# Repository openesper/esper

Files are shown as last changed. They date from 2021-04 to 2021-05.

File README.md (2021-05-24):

Imgur

# About Esper

Heavily inspired by the [Pi-Hole](https://github.com/pi-hole/pi-hole), this project aims to bring network wide ad-blocking to another popular device popular among makers and hobbyists, the ESP32.

## What is DNS?

Commonly referred to as the "phone book for the internet", the DNS protocol is how devices map human readable urls like google.com or facebook.com into IP addresses that the device can use.

## How does Esper block ads?

Just like the [Pi-Hole](https://github.com/pi-hole/pi-hole), Esper acts as a DNS server for devices. When sent a DNS query, Esper will read the url the device is requesting, then decide to block the request by returning 0.0.0.0 or forward the request on to a real DNS server.

## Differences between Pi-hole and Esper

The biggest, and most obvious difference is the hardware these projects run on. Pi-hole aims to be available on any Linux powered hardware, while Esper is an ESP32 specific project. Due to being run on a microcontroller, Esper is much more limited in it's capabilities and is therefore much more minimal in it's design.

## Why choose Esper instead of Pi-hole?

Choose whatever one suits you! If you like tinkering with hardware, and do not have much experience with the Raspberry Pi/Linux ecosystem, setting up the Esper software on an ESP32 dev board might be an interesting project. And while Esper may not be nearly as powerful as a Raspberry Pi, DNS protocol is very lightweight in nature. Unless you are in a household with 10+ people that are always online you will likely never going to need more computing power than a microcontroller can provide.

At the same time, if you have no problem using a shell and Linux environment, the Pi-hole is a much more feature rich and powerful piece of software that is a joy to use.

## How can I get an Esper?

The easiest way, is to purchase a pre-made one from the [Tindie store](https://www.tindie.com/products/esper/esper/).

If you have some ESP32 development boards collecting dust, it will work on those too! ([Just follow the instructions here!](https://github.com/openesper/esper/blob/main/software/README.md))

DISCLAIMER: It is **heavily** recommended to use a device with ethernet. Even the best Wifi will significantly increase latency and decrease reliability compared to a good copper connection.

If you want to try you hand an making an Esper from scratch, the repository contains all the schematic, pcb, and enclosure files needed to build one yourself.

## Reprogramming Esper

Do you like the Esper hardware, but want to use it for something other than ad-blocking? Great! The Esper hardware is completely reprogrammable and includes an on-board USB-UART converter, no extra programmers are needed!

# Esper Development

## Tools Used

* KiCAD	- EDA tool used to design PCB
* FreeCAD - 3D modeling tool for designing enclosure
* ESP-IDF - Contains ESP32 API and build tools for firmware development
* Python 3.7 - Scripts to glue everything together

## Directory Structure

    ├── hardware                    # Hardware root directory
    │   ├── custom components           # Custom KiCad component files
    │   ├── enclosure                   # FreeCAD project and STL files for enclosure
    │   ├── product                     # KiCad projects for Esper
    │   │   ├── usb-programmable        	# Includes CP2102 for easy usb programming
    │   │   └── jtag-header             	# 10-pin header for JTAG & UART, meant to be used with programmer
    │   └── programmer                  # KiCad project for programmer/debugger
    └── software                    # Software root directory
        ├── firmware                    # ESP-IDF project that contains all code for Esper
        ├── scripts                     # Scripts used in build process and testing
        └── website                     # For website development, contains symbolic links to HTML files

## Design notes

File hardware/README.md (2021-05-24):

PCB

# Esper Hardware Design

## Goals

All Esper hardware is designed to be as easy to modify and manufacture as possible. For the most part this means using free, open-source tools and simplifying the design to have the smallest DOM possible. 

### PCB & Schematic

KiCAD is used for all PCB design since it is free and has a large community support. 

### Manufacturing

The Esper device is designed to be manufactured and assembled at JLCPCB. At low quantities (5-10 boards), no other board house comes close on price and ease of use.

This may change in the future if other companies start matching JLCPCB in price, or if Esper starts being manufactures at higher volumes.

### Part Selection

To make the process of manufacturing and assembly as easy as possible, all components (except connectors) are chosen from the [JLCPCB parts library](https://jlcpcb.com/parts) so JLCPCB assembly service can be used. This means that connectors are the only parts that need to be hand soldered, but JLC recently added connectors to their parts library so this may change soon.

Also, in order to minimize the amount of work needed to keep custom schematic symbols and footprints up-to-date, it was a priority to minimize the amount of custom components and only use parts found in the default KiCAD library. Almost every part in the project has footprints and symbols included in KiCAD, or has an equivalent component included.

### Enclosure

There are many 3D modeling tools out there, to varying degrees of free-ness, but I am not qualified to go over the pros and cons of each. FreeCAD was chosen for this project simply because it seemed to be the most popular open-source program, but almost any would work.

The enclosure is currently designed to be 3D printed, but alternatives are being looked into.

## BOM

To fully assemble an Esper, these parts are needed:

| Part | Quantity |
| --- | --- |
| Enclosure Top | 1 |
| Enclosure Bottom | 1 |
| Enclosure Dome | 1 |
| Esper PCBA | 1 |
| [Heat-Set Inserts (M2 x 0.4mm) x 2.5mm](https://www.mcmaster.com/catalog/127/3973) | 2 |
| [Screws (M2 x 0.4mm) x 6mm](https://www.mcmaster.com/catalog/127/3251) | 2 |

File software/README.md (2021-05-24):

Esper

# Esper Software

## Installation

### Arduino

At the moment there is no support for the Arduino environment yet, but it is being worked on.

### Requirements

In order to build and flash Esper, you will first need to [install ESP-IDF](https://docs.espressif.com/projects/esp-idf/en/latest/esp32/get-started/#installation-step-by-step) then [set up the ESP-IDF environment.](https://docs.espressif.com/projects/esp-idf/en/latest/esp32/get-started/index.html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). It is recommended to 
get one of the "hello world" example projects working before flashing Esper, just to verify that your toolchain is working.

After getting ESP-IDF setup, you will have to install the filesystem that Esper uses (LittleFS). This can be done with:

    cd esper
    git submodule init

### Configuration

Before building the Esper firmware, you will have to do some configuration first. If you are using a ESP32 development board, such as the ESP32 DevKitC, you will only have to enter
your wifi credentials. If you have other hardware, and you want to use ethernet or LEDs, then you will have to enable those features and then enter their respective GPIO numbers.

To edit the configuration, simply enter these commands:

    cd software/firmware
    idf.py menuconfig

Then configure the options under Esper Configuration to match your device's capabilities.

### Building & Flashing

After installing ESP-IDF, build and flash your device by running these commands (must be executed from firmware directroy)

    idf.py build
    idf.py -p PORT [-b BAUD] erase
    idf.py -p PORT [-b BAUD] flash monitor

### Issues

If you have any issues, [this section](https://docs.espressif.com/projects/esp-idf/en/latest/esp32/get-started/index.html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) may be able to help.

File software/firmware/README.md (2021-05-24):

# Esper Firmware

This is an ESP-IDF project, written entirely in C/C++. For an explination of the project structure and files, [the espressif docs](https://docs.espressif.com/projects/esp-idf/en/latest/esp32/api-guides/build-system.html) are a good place to start.

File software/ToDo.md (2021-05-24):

## TODO:

### Tests:
- Start writing test doc
- Start incorporating unit testing
### Build
- Add Arduino support
### Web
- Password authentication
- Analytics
    - Total queries and total blocked queries
    - most blocked/queried websites
- show currently connected network & ip
- show connected clients
- Upload/download blacklist files
### Debugging
- Add debug page to website
- Add errors to error log
### DATETIME
- Add timezone select
### CONFIGURATION
- Look into wifi_provisioning library
### DNS
- Support for non A/AAAA types
- Reverse DNS support
- Benchmark DNS response times
### LEDs
- LED Error Codes

## Maybe Some Day:
- DHCP support
    - Individual block lists for devices
    - User accounts??
- DNS Over HTTPS (early tests dont look hopeful for ESP32, will likely need MPU)

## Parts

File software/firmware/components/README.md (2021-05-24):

# Directory of all components used in project

### Datetime

Used to get time from SNTP server

### DNS

All DNS related activities, including logging, are in here. This is where the socket, listening on port 53, is created and then parses any packets it receives.

### Error

This is where the ATTEMPT, TRY, and THROWE macros are, as well as most errors are defined. 

### Events

This component keeps track of the current state of the module using a FreeRTOS event group.

### Flash

Filesystem initialization and usage, as well as all of the files that will be embedded into the app binary

### GPIO

LED and button functions. LED task it notified any time the current state of the device is changed and updates accordingly.

### HTTP

This is the largest component. It stores all the code for both the application website.

### Lists

All functions that relate to the blacklist are in here.

### Lists

All functions that relate to the blacklist are in here.

### LittleFS

Submodule that contains the LittleFS filesystem, which is an alternative to SPIFFS.

### NetIF

Ethernet and Wifi code. Not used much after device is initialized and running.

### OTA

Over-The-Air updates. This contains the tasks that periodically check for updates and then writes the new update to flash.

### Settings

All functions related to parsing/editing the settings.json file

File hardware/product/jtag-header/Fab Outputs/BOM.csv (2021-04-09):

Comment | Designator | Footprint | LCSC
1uF | C1,C4,C9 | Capacitor_SMD:C_0402_1005Metric | C52923
10uF | C3,C10 | Capacitor_SMD:C_0805_2012Metric | C15850
0.1uF | C2,C5,C6,C7,C8,C11 | Capacitor_SMD:C_0402_1005Metric | C1525
GRN | D1 | Diode_SMD:D_0603_1608Metric | C72043
RS-3535MWAR | D2 | LED_SMD:LED_RGB_PLCC-6 | C110402
Ferrite_Bead | FB2 | Inductor_SMD:L_0805_2012Metric | C1015
MountingHole | H1,H2 | MountingHole:MountingHole_2.2mm_M2_Pad
USB_B_Micro | J1 | Connector_USB:USB_Micro-B_Molex-105017-0001
Conn_02x05_Odd_Even | J2 | EsperFootprints:CNC_3220-10-0100-00
RJ45_Amphenol_RJMG1BD3B8K1ANR | J3 | Connector_RJ:RJ45_Amphenol_RJMG1BD3B8K1ANR
2N7002 | Q1,Q2,Q3 | Package_TO_SOT_SMD:SOT-23 | C8545
470 | R1 | Resistor_SMD:R_0402_1005Metric | C25117
10K | R2,R8,R10,R11,R12,R24 | Resistor_SMD:R_0402_1005Metric | C25744
270 | R17,R21 | Resistor_SMD:R_0603_1608Metric | C22966
12.1K | R23 | Resistor_SMD:R_0402_1005Metric | C25852
47 | R3,R4 | Resistor_SMD:R_0603_1608Metric | C23182
82 | R5 | Resistor_SMD:R_1206_3216Metric | C247183
49.9 | R6,R7,R9,R13,R14,R15,R16,R18,R19,R20,R22 | Resistor_SMD:R_0402_1005Metric | C25120
PTS645VH83-2 LFS | SW1 | Button_Switch_THT:SW_Tactile_SPST_Angled_PTS645Vx83-2LFS
AZ1117EH-3.3TRG1 | U1 | Package_TO_SOT_SMD:SOT-223 | C108494
ESP32-WROOM-32E | U2 | RF_Module:ESP32-WROOM-32 | C701341
LAN8720A | U3 | Package_DFN_QFN:QFN-24-1EP_4x4mm_P0.5mm_EP2.6x2.6mm_ThermalVias | C45223

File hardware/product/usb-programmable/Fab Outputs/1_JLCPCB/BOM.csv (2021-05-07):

Comment | Designator | Footprint | LCSC
1uF | C1,C4,C12 | Capacitor_SMD:C_0402_1005Metric | C52923
10uF | C3,C10,C15 | Capacitor_SMD:C_0402_1005Metric | C15525
0.1uF | C2,C5,C6,C7,C11,C13,C14,C16 | Capacitor_SMD:C_0402_1005Metric | C1525
GRN | D1 | Diode_SMD:D_0603_1608Metric | C72043
RS-3535MWAR | D2 | LED_SMD:LED_RGB_PLCC-6 | C110402
Ferrite_Bead | FB2 | Inductor_SMD:L_0805_2012Metric | C1015
MountingHole | H1,H2 | MountingHole:MountingHole_2.2mm_M2_Pad
USB_B_Micro | J1 | Connector_USB:USB_Micro-B_Molex-105017-0001
RJ45_Amphenol_RJMG1BD3B8K1ANR | J3 | Connector_RJ:RJ45_Amphenol_RJMG1BD3B8K1ANR
2N7002 | Q1,Q2,Q3,Q4,Q5 | Package_TO_SOT_SMD:SOT-23 | C8545
470 | R1 | Resistor_SMD:R_0402_1005Metric | C25117
2.2k | R10,R12,R21,R23,R24,R25,R26,R27,R28 | Resistor_SMD:R_0402_1005Metric | C25879
270 | R11,R17 | Resistor_SMD:R_0603_1608Metric | C22966
10K | R2,R8 | Resistor_SMD:R_0402_1005Metric | C25744
4.87 | R29 | Resistor_SMD:R_0402_1005Metric | C25902
47 | R3,R4 | Resistor_SMD:R_0603_1608Metric | C23182
82 | R5 | Resistor_SMD:R_1206_3216Metric | C247183
49.9 | R6,R7,R9,R13,R14,R15,R16,R18,R19,R20,R22 | Resistor_SMD:R_0402_1005Metric | C25120
PTS645VH83-2 LFS | SW1 | Button_Switch_THT:SW_Tactile_SPST_Angled_PTS645Vx83-2LFS
AZ1117EH-3.3TRG1 | U1 | Package_TO_SOT_SMD:SOT-223 | C108494
ESP32-WROOM-32E | U2 | RF_Module:ESP32-WROOM-32 | C701341
CP2102-GMR_NRND | U4 | EsperFootprints:VFQFN-28-1EP_5x5mm | C6568
DP83848C | U5 | Package_QFP:LQFP-48_7x7mm_P0.5mm | C16688

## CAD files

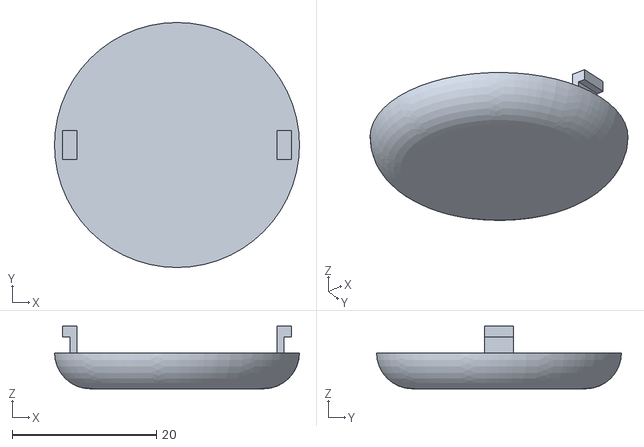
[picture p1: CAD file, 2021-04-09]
hardware/enclosure/EnclosureDome.stl
34.0 x 34.0 x 8.70

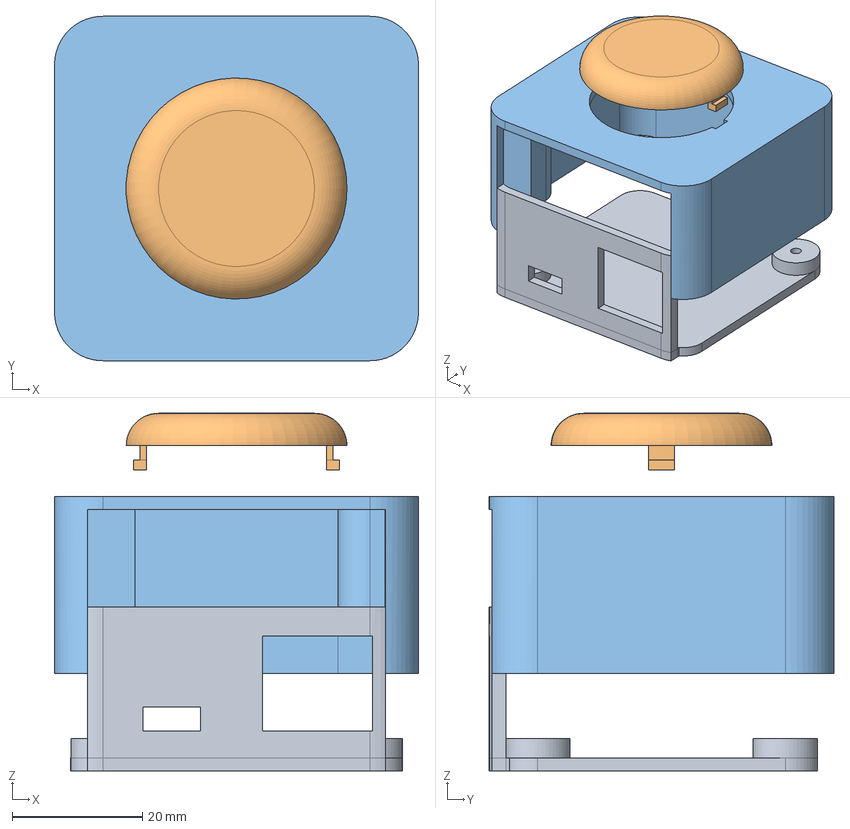
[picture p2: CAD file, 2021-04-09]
hardware/enclosure/Enclosure.FCStd
56.0 x 53.0 x 55.0 mm
Enclosure Bottom
Enclosure Dome
Enclosure Top

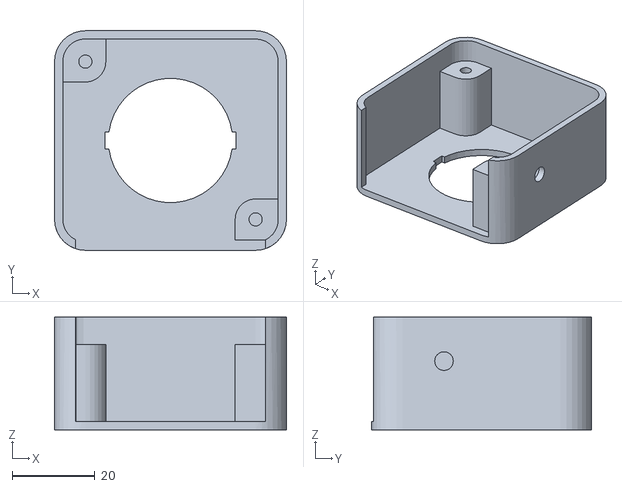
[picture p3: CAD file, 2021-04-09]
hardware/enclosure/EnclosureTop.stl
56.0 x 53.0 x 27.2

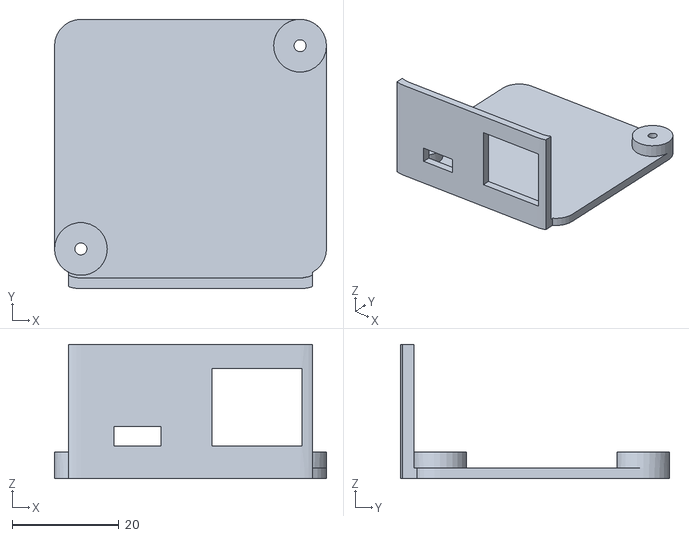
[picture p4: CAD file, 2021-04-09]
hardware/enclosure/EnclosureBottom.stl
51.0 x 50.5 x 25.2

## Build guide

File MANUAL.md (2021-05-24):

# Esper Manual

## Setting up Esper
In order for Esper to block ads, your devices have to be told to use it as their DNS server. You can do this individually for each device by going into their internet/wifi settings and manually changing the assigned DNS server, or you can do it for every device on your network at once by editing the DNS settings in your router. Unfortunately every router has a different method of configuration, so you will have to search for instructions online on how to set IP addresses in your router.

It may take a few minutes for your devices to update their DNS server, but after this point Esper will be monitoring DNS requests on your network. 
To verify that it is working simply go to http://esper.com (not "https://" !!), and if you are presented with the Esper homepage it is working! 
If not, then something may have gone wrong with the device or DNS server configuration

## Finding Esper's IP

Similar to before, you will have to go into your router's settings and look for Esper's IP there. Most routers have a "connected devices" page that can be helpful. 

## Configuration
Esper ships with a default blacklist of websites so it will start blocking well known ad hosting websites as soon as it is configured as your DNS server. If you still notice
ads coming through, check the recent queries for domain names like "ads.website.com" or "analytics.com" and press the 'X' next to them to add them to the device's blacklist.

### First-Part Ads
Unfortunately, some websites such as Youtube and Hulu serve ads from their own domain (e.g. "youtube.com" and "hulu.com"). Attempting to block these domains will just block some
or the entire website. At the moment there is no way around this other than installing a browser based ad blocker such as uBlock Origin.

## LEDs
The color of the esper displays the current status of the device.
- Purple - Initializing
- Blue - Blocking
- Weak Blue - Not blocking
- Red - Error

## Button
The button on the side will cause the device to do one of two things depending on how long it is held down.
- Less than 0.5 seconds: toggle blocking status
- More than 8 seconds: Factory reset

# FAQ
This is still being developed, but [this post on Reddit](https://old.reddit.com/r/pihole/comments/frum61/frequently_asked_questions/) goes over some common problems setting up
Pi-hole and may be helpful if you are having a similar problem with Esper. For all other questions, send an to email esper@openesper.com.

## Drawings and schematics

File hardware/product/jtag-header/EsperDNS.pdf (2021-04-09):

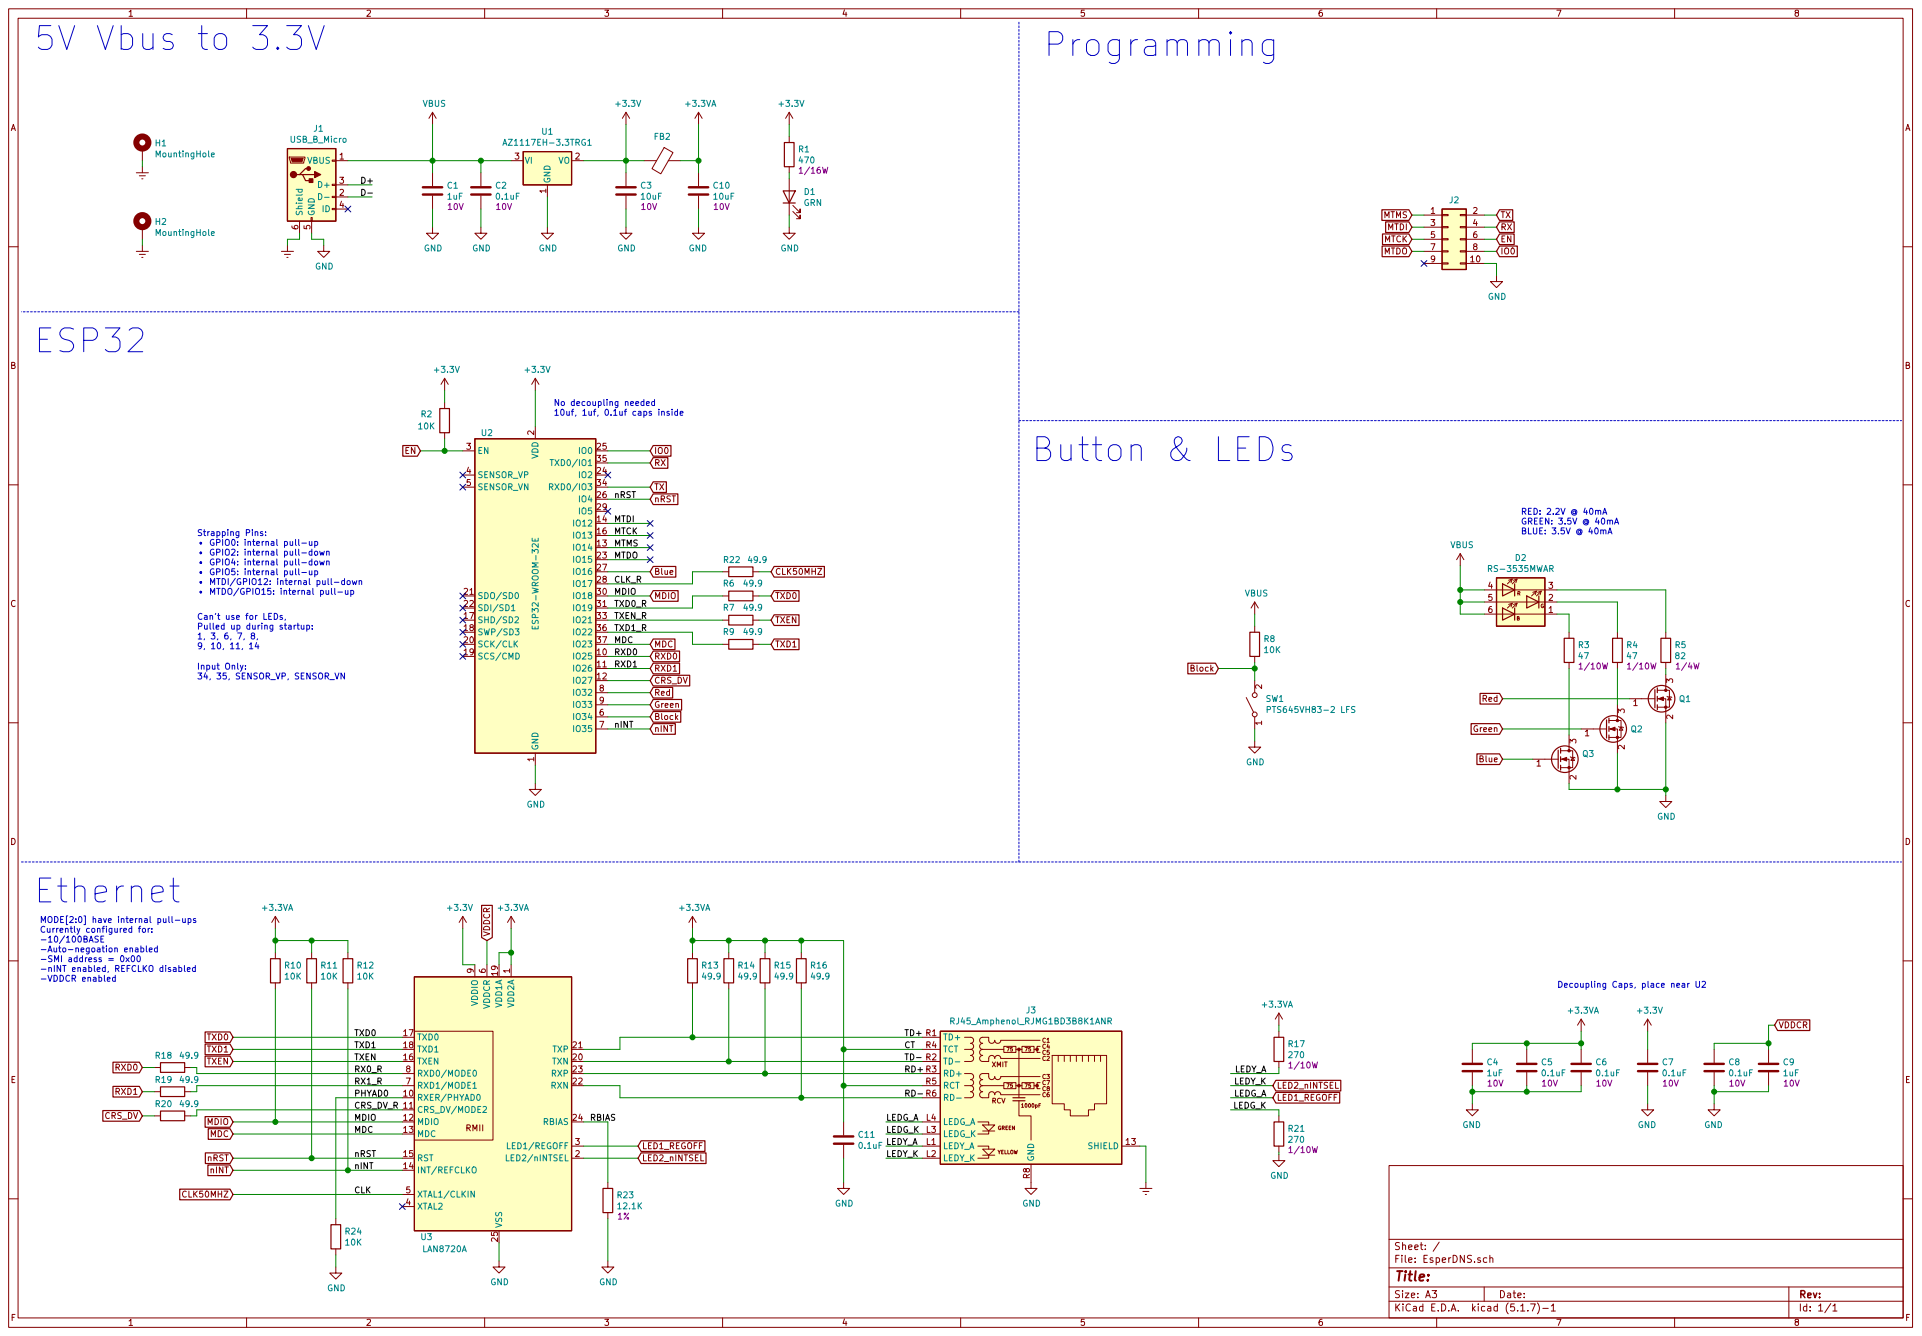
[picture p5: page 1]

1 VO 2 VI 3 U1 AZ1117EH-3.3TRG1 GND GND

2 SCK/CLK 20 SDO/SD0 21 SDI/SD1 22

GPIO0: internal pull-up
GPIO2: internal pull-down
GPIO4: internal pull-down
GPIO5: internal pull-up
MTDI/GPIO12: internal pull-down
MTDO/GPIO15: internal pull-up

Block nRST CLK50MHZ MDIO MDC

MODE[2:0] have internal pull-ups
Currently configured for: -10/100BASE

-Auto-negoation enabled
-SMI address = 0x00
-nINT enabled, REFCLKO disabled

TD- TD+ RD- nRST
nINT PHYAD0
CRS_DV_R
CLK MDIO MDC

File: EsperDNS.sch Sheet: /

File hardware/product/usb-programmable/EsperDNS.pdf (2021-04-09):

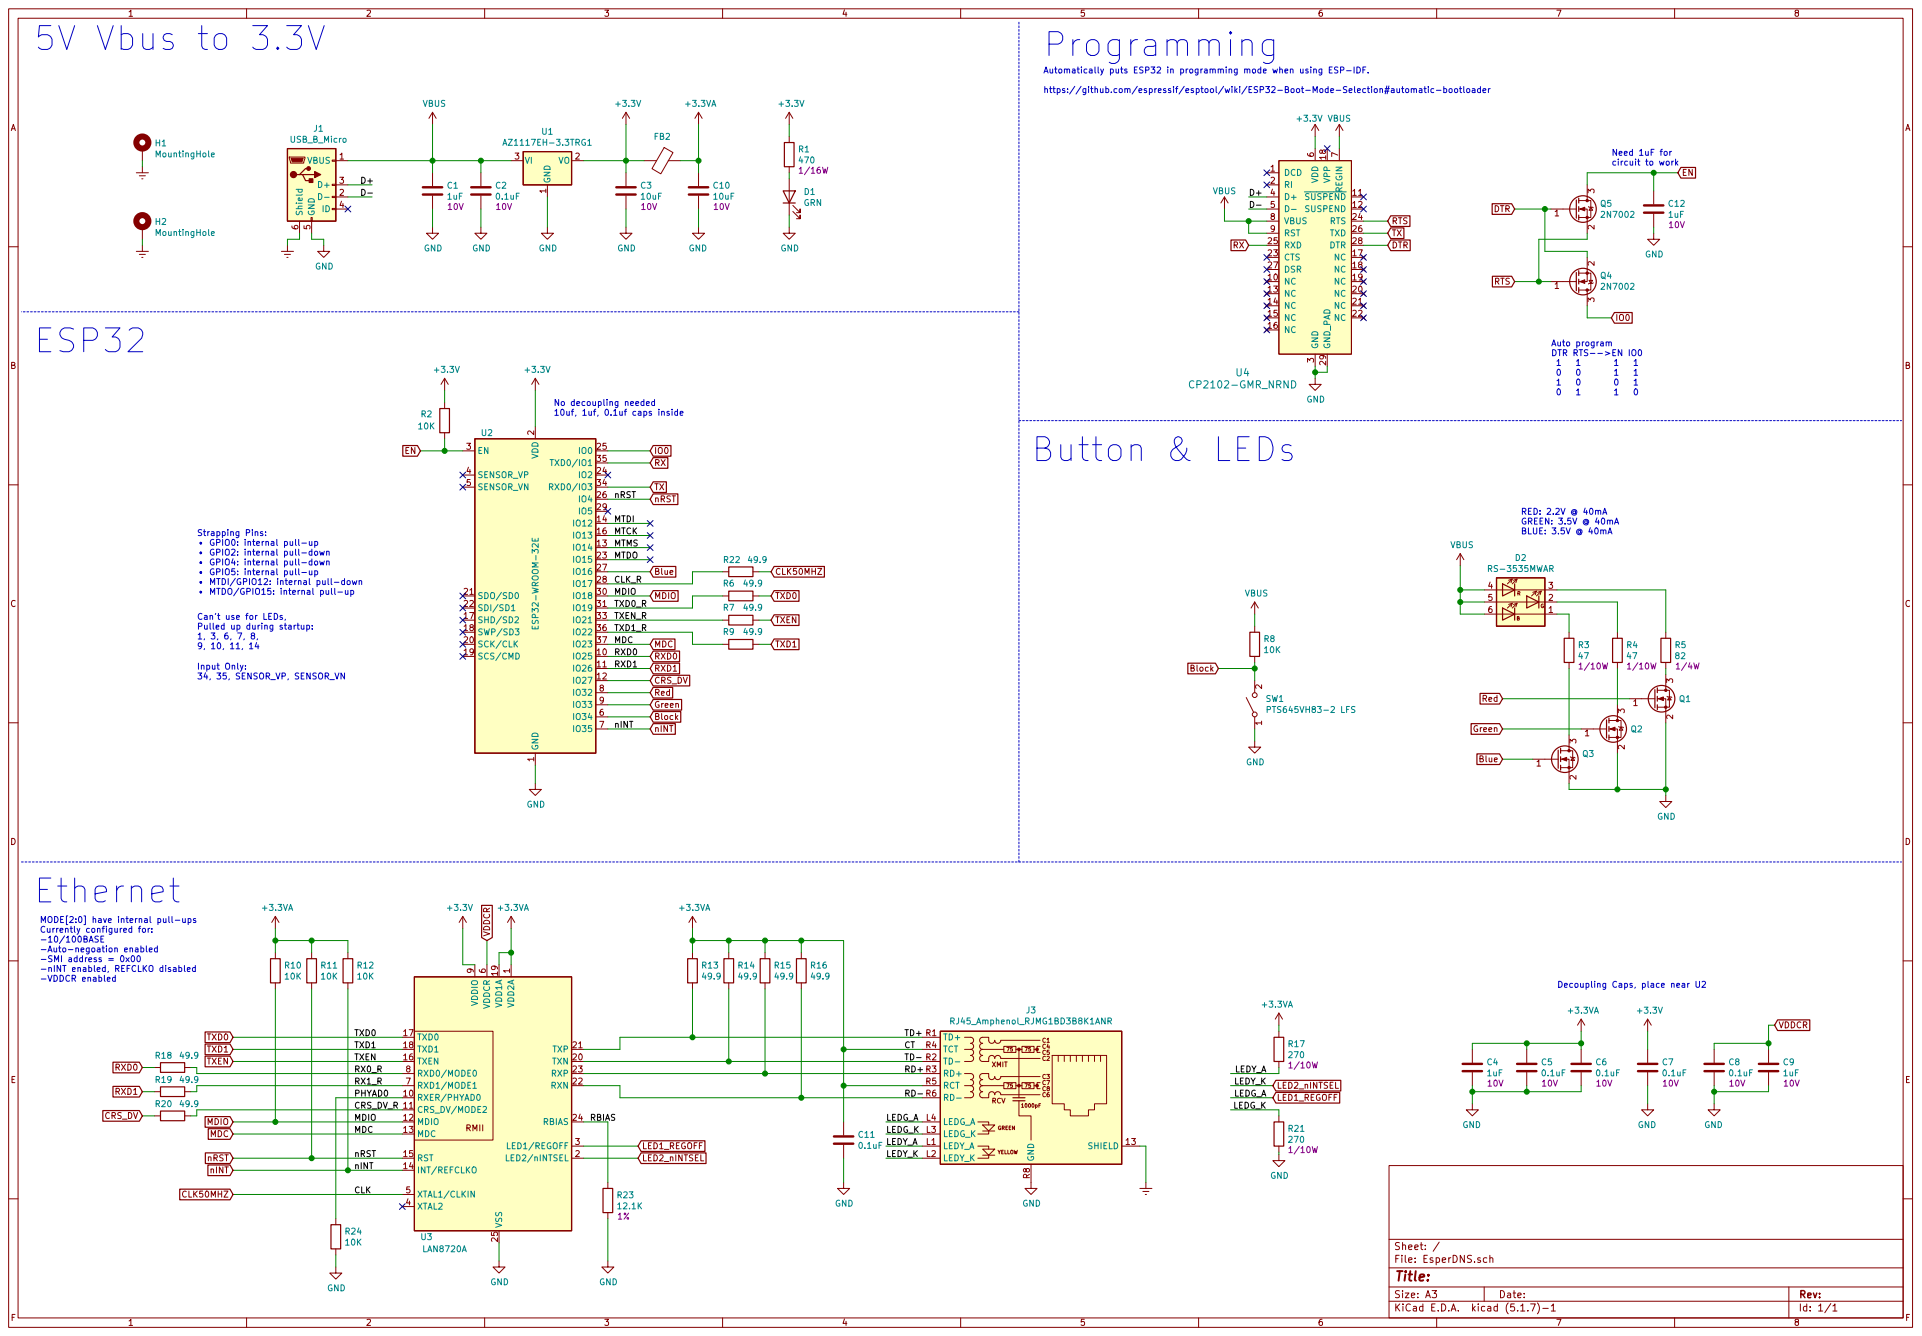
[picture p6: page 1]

-VDDCR enabled 5V Vbus to 3.3V

Automatically puts ESP32 in programming mode when using ESP-IDF.

https://github.com/espressif/esptool/wiki/ESP32-Boot-Mode-Selection#automatic-bootloader

1 VO 2 VI 3 U1 AZ1117EH-3.3TRG1 VBUS GND

Need 1uF for circuit to work ESP32

7 VBUS 8 RST 9 NC 10 NC 20 SUSPEND 11 NC 21 SUSPEND 12 NC 22 NC 13 CTS 23 NC 14 RTS 24 NC 15 RXD 25 NC 16 TXD 26 NC 17 DSR 27 NC 18 VPP 18 DTR 28 NC 19 GND_PAD 29 U4 CP2102-GMR_NRND

nRST MDC MDIO
MTDO MTMS MTCK MTDI CLK_R

2 SCK/CLK 20 SDO/SD0 21 SDI/SD1 22

BLUE: 3.5V @ 40mA MODE[2:0] have internal pull-ups

Strapping Pins:
GPIO0: internal pull-up
GPIO2: internal pull-down
GPIO4: internal pull-down
GPIO5: internal pull-up
MTDI/GPIO12: internal pull-down
MTDO/GPIO15: internal pull-up

-Auto-negoation enabled
-SMI address = 0x00
-nINT enabled, REFCLKO disabled

Decoupling Caps, place near U2

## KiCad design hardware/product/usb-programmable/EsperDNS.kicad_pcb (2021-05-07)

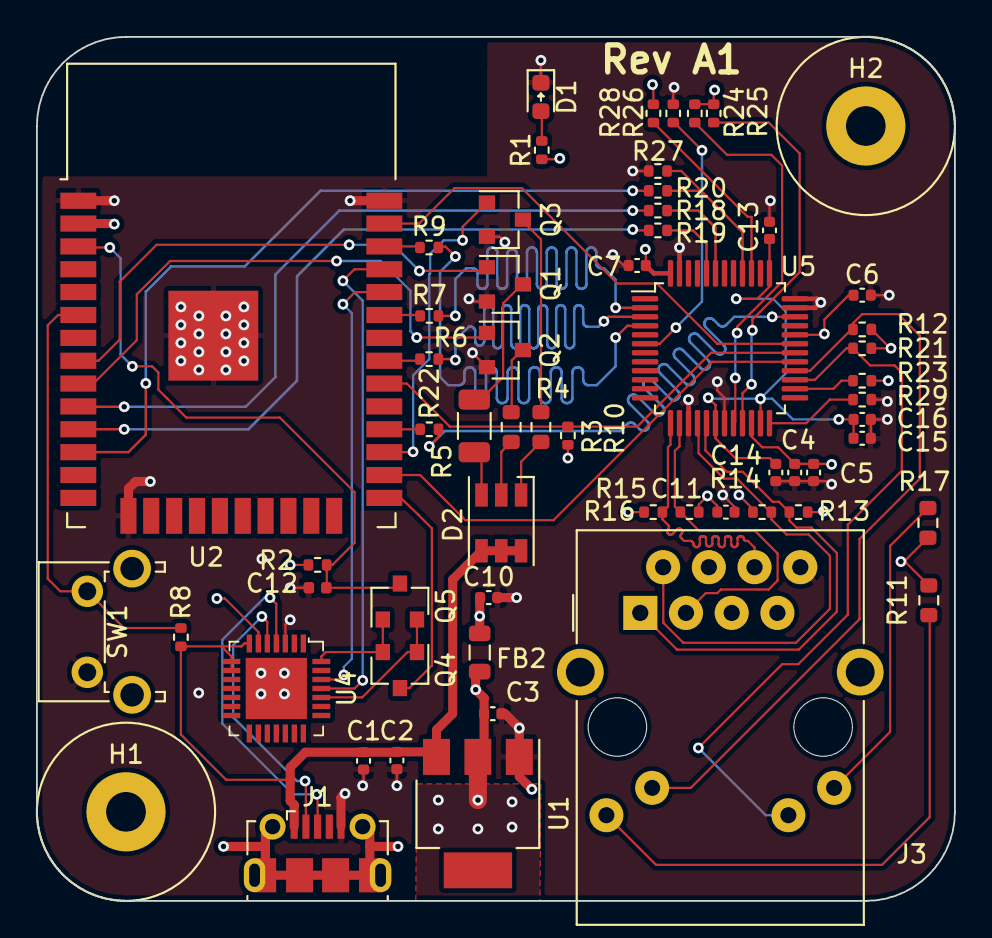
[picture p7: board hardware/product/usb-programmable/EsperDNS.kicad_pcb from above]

Board: 4 copper layers, 51.0 x 48.0 mm, 60 parts (0 on the bottom side), 56 nets.

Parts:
C1, C4, C12: 1uF; C_0402_1005Metric
C2, C5, C6, C7, C11, C13, C14, C16: 0.1uF; C_0402_1005Metric
C3, C10, C15: 10uF; C_0402_1005Metric
D1: GRN; D_0603_1608Metric
D2: RS-3535MWAR; LED_RGB_PLCC-6
FB2: Ferrite_Bead; L_0805_2012Metric
H1, H2: MountingHole; MountingHole_2.2mm_M2_Pad
J1: USB_B_Micro; USB_Micro-B_Molex-105017-0001
J3: RJ45_Amphenol_RJMG1BD3B8K1ANR
Q1, Q2, Q3, Q4, Q5: 2N7002; SOT-23
R1: 470; R_0402_1005Metric
R2, R8: 10K; R_0402_1005Metric
R3, R4: 47; R_0603_1608Metric
R5: 82; R_1206_3216Metric
R6, R7, R9, R13, R14, R15, R16, R18, R19, R20, R22: 49.9; R_0402_1005Metric
R10, R12, R21, R23, R24, R25, R26, R27, R28: 2.2k; R_0402_1005Metric
R11, R17: 270; R_0603_1608Metric
R29: 4.87; R_0402_1005Metric
SW1: PTS645VH83-2 LFS; SW_Tactile_SPST_Angled_PTS645Vx83-2LFS
U1: AZ1117EH-3.3TRG1; SOT-223
U2: ESP32-WROOM-32E; ESP32-WROOM-32
U4: CP2102-GMR_NRND; VFQFN-28-1EP_5x5mm
U5: DP83848C; LQFP-48_7x7mm_P0.5mm

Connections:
+3.3VA: C4.1, C5.1, C10.1, C11.1, FB2.1, J3.R4, J3.R5, R11.1, R13.1, R14.1, R15.1, R16.1, R17.1, U5.22
+3V3: C3.1, C6.1, C7.1, FB2.2, R1.1, R2.2, R10.1, R12.1, R21.1, R23.1, R24.1, R25.1, R26.1, U1.2, U2.2, U4.6, U5.32, U5.48
/CLK_R: R22.2, U2.28
/CRS_DV_R: R20.1, R27.1, U5.40
/D+: J1.3, U4.4
/D-: J1.2, U4.5
/LEDG_A: J3.L4, R11.2
/LEDY_A: J3.L1, R17.2
/LED_ACT: R23.2, U5.26
/LED_LINK: J3.L3, R12.2, U5.28
/LED_SPEED: J3.L2, R21.2, U5.27
/MII_MODE: R26.2, U5.39
/PFB: C13.1, C14.1, C15.1, C16.1, U5.18, U5.23, U5.37
/RBIAS: R29.1, U5.24
/RD+: J3.R3, R15.2, U5.14
/RD-: J3.R6, R16.2, U5.13
/RESERVED0: R24.2, U5.20
/RESERVED1: R25.2, U5.21
/RX0_R: R18.1, U5.43
/RX1_R: R19.1, U5.44
/SNI_MODE: R28.1, U5.6
/TD+: J3.R1, R13.2, U5.17
/TD-: J3.R2, R14.2, U5.16
/TXD0_R: R6.1, U2.31
/TXD1_R: R9.1, U2.36
/TXEN_R: R7.1, U2.33
Block: R8.2, SW1.2, U2.6
Blue: Q3.1, U2.27
CLK_RMII: R22.1, U5.34
CRS_DV: R20.2, U2.12
DTR: Q4.2, Q5.1, U4.28
EN: C12.1, Q5.3, R2.1, U2.3
Earth: H1.1, H2.1, J1.6, J3.13
GND: C1.2, C2.2, C3.2, C4.2, C5.2, C6.2, C7.2, C10.2, C11.2, C12.2, C13.2, C14.2, C15.2, C16.2, D1.1, J1.5, J3.R8, Q1.2, Q2.2, Q3.2, R27.2, R28.2, R29.2, SW1.1, U1.1, U2.1, U2.15, U2.38, U2.39, U4.3, U4.29, U5.15, U5.19, U5.35, U5.36, U5.47
Green: Q2.1, U2.9
IO0: Q4.3, U2.25
MDC: U2.37, U5.31
MDIO: R10.2, U2.30, U5.30
unnamed: D1.2, R1.2
unnamed: D2.1, R3.1
unnamed: D2.2, R4.1
unnamed: D2.3, R5.1
unnamed: Q1.3, R5.2
unnamed: Q2.3, R4.2
unnamed: Q3.3, R3.2
RTS: Q4.1, Q5.2, U4.24
RX: U2.35, U4.25
RXD0: R18.2, U2.10
RXD1: R19.2, U2.11
Red: Q1.1, U2.8
TX: U2.34, U4.26
TXD0: R6.2, U5.3
TXD1: R9.2, U5.4
TXEN: R7.2, U5.2
VBUS: C1.1, C2.1, D2.4, D2.5, D2.6, J1.1, R8.1, U1.3, U4.7, U4.8, U4.9
nRST: U2.26, U5.29

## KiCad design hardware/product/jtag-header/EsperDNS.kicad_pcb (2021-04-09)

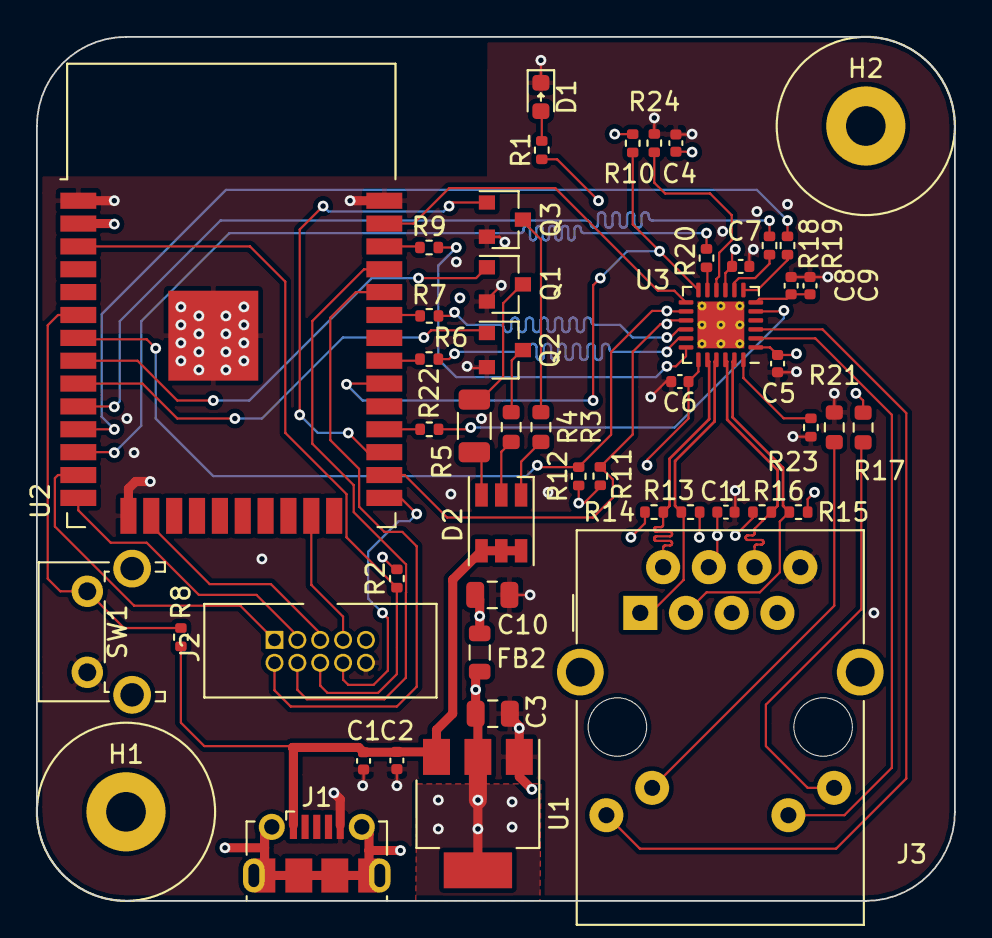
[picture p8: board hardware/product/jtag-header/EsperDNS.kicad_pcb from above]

Board: 4 copper layers, 51.0 x 48.0 mm, 50 parts (0 on the bottom side), 53 nets.

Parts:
C1, C4, C9: 1uF; C_0402_1005Metric
C2, C5, C6, C7, C8, C11: 0.1uF; C_0402_1005Metric
C3, C10: 10uF; C_0805_2012Metric
D1: GRN; D_0603_1608Metric
D2: RS-3535MWAR; LED_RGB_PLCC-6
FB2: Ferrite_Bead; L_0805_2012Metric
H1, H2: MountingHole; MountingHole_2.2mm_M2_Pad
J1: USB_B_Micro; USB_Micro-B_Molex-105017-0001
J2: Conn_02x05_Odd_Even; CNC_3220-10-0100-00
J3: RJ45_Amphenol_RJMG1BD3B8K1ANR
Q1, Q2, Q3: 2N7002; SOT-23
R1: 470; R_0402_1005Metric
R2, R8, R10, R11, R12, R24: 10K; R_0402_1005Metric
R3, R4: 47; R_0603_1608Metric
R5: 82; R_1206_3216Metric
R6, R7, R9, R13, R14, R15, R16, R18, R19, R20, R22: 49.9; R_0402_1005Metric
R17, R21: 270; R_0603_1608Metric
R23: 12.1K; R_0402_1005Metric
SW1: PTS645VH83-2 LFS; SW_Tactile_SPST_Angled_PTS645Vx83-2LFS
U1: AZ1117EH-3.3TRG1; SOT-223
U2: ESP32-WROOM-32E; ESP32-WROOM-32
U3: LAN8720A; QFN-24-1EP_4x4mm_P0.5mm_EP2.6x2.6mm_ThermalVias

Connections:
+3.3VA: C4.1, C5.1, C6.1, C10.1, C11.1, FB2.1, J3.R4, J3.R5, R10.1, R11.1, R12.1, R13.1, R14.1, R15.1, R16.1, R17.1, U3.1, U3.19
+3V3: C3.1, C7.1, FB2.2, R1.1, R2.2, U1.2, U2.2, U3.9
/CLK_R: R22.2, U2.28
/CRS_DV_R: R20.1, U3.11
/LEDG_K: J3.L3, R21.1
/LEDY_A: J3.L1, R17.2
/PHYAD0: R24.1, U3.10
/RBIAS: R23.1, U3.24
/RD+: J3.R3, R15.2, U3.23
/RD-: J3.R6, R16.2, U3.22
/RX0_R: R18.1, U3.8
/RX1_R: R19.1, U3.7
/TD+: J3.R1, R13.2, U3.21
/TD-: J3.R2, R14.2, U3.20
/TXD0_R: R6.1, U2.31
/TXD1_R: R9.1, U2.36
/TXEN_R: R7.1, U2.33
Block: R8.2, SW1.2, U2.6
Blue: Q3.1, U2.27
CLK50MHZ: R22.1, U3.5
CRS_DV: R20.2, U2.12
EN: J2.6, R2.1, U2.3
Earth: H1.1, H2.1, J1.6, J3.13
GND: C1.2, C2.2, C3.2, C4.2, C5.2, C6.2, C7.2, C8.2, C9.2, C10.2, C11.2, D1.1, J1.5, J2.10, J3.R8, Q1.2, Q2.2, Q3.2, R21.2, R23.2, R24.2, SW1.1, U1.1, U2.1, U2.15, U2.38, U2.39, U3.25
Green: Q2.1, U2.9
IO0: J2.8, U2.25
LED1_REGOFF: J3.L4, U3.3
LED2_nINTSEL: J3.L2, U3.2
MDC: U2.37, U3.13
MDIO: R10.2, U2.30, U3.12
MTCK: J2.5, U2.16
MTDI: J2.3, U2.14
MTDO: J2.7, U2.23
MTMS: J2.1, U2.13
unnamed: D1.2, R1.2
unnamed: D2.1, R3.1
unnamed: D2.2, R4.1
unnamed: D2.3, R5.1
unnamed: Q1.3, R5.2
unnamed: Q2.3, R4.2
unnamed: Q3.3, R3.2
RX: J2.4, U2.35
RXD0: R18.2, U2.10
RXD1: R19.2, U2.11
Red: Q1.1, U2.8
TX: J2.2, U2.34
TXD0: R6.2, U3.17
TXD1: R9.2, U3.18
TXEN: R7.2, U3.16
VBUS: C1.1, C2.1, D2.4, D2.5, D2.6, J1.1, R8.1, U1.3
VDDCR: C8.1, C9.1, U3.6
nINT: R12.2, U2.7, U3.14
nRST: R11.2, U2.26, U3.15

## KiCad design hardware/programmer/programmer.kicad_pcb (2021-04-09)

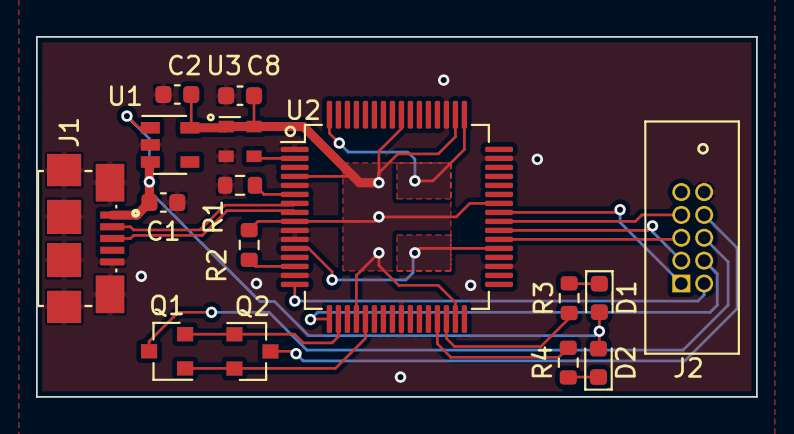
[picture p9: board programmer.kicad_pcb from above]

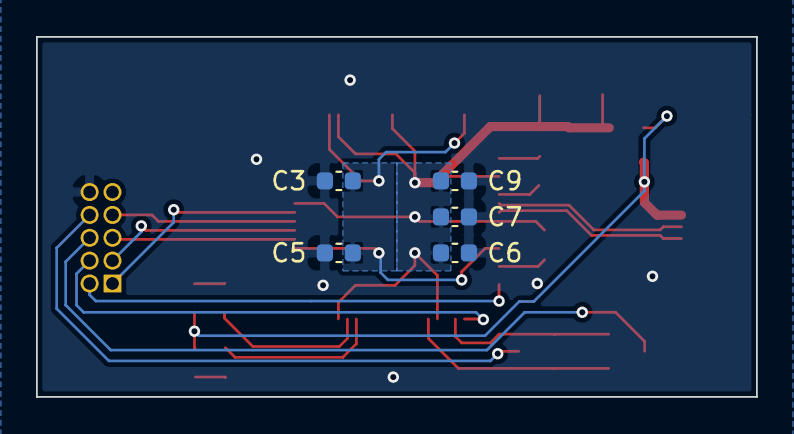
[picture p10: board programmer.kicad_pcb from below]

Board: 2 copper layers, 40.0 x 20.0 mm, 21 parts (5 on the bottom side), 23 nets.

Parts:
C1, C2, C5, C6, C7, C8, C9: 0.1uF; C_0603_1608Metric
C3: 1uF; C_0603_1608Metric
D1: BLU; LED_0603_1608Metric
D2: GRN; LED_0603_1608Metric
J1: 10118192-0001LF; AMPHENOL_10118192-0001LF
J2: 3220-10-0100-00; CNC_3220-10-0100-00
Q1, Q2: 2N7002ET1G; SOT-23
R1, R2: 12K; R_0603_1608Metric
R3, R4: 470; R_0603_1608Metric
U1: TLV75533PDBV; SOT-23-5
U2: FT2232HL; LQFP-64_10x10mm_P0.5mm
U3: ASDMB-12.000MHz; Oscillator_SMD_Abracon_ASDMB-4Pin_2.5x2.0mm

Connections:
+1V8: C3.1, C5.1, U2.12, U2.37, U2.49, U2.64
+3V3: C2.1, C6.1, C7.1, C8.1, C9.1, R2.2, U1.5, U2.4, U2.9, U2.20, U2.31, U2.42, U2.50, U2.56, U3.1, U3.4
/OSCI: U2.2, U3.3
/REF: R1.1, U2.6
/RESET: R2.1, U2.14
D+: J1.3, U2.8
D-: J1.2, U2.7
DTR#: Q1.1, Q2.2, U2.21
EN: J2.6, Q1.3
GND: C1.2, C2.2, C3.2, C5.2, C6.2, C7.2, C8.2, C9.2, J1.5, J1.6, J2.10, R1.2, U1.2, U2.1, U2.5, U2.10, U2.11, U2.13, U2.15, U2.25, U2.35, U2.47, U2.51, U3.2
IO0: J2.8, Q2.3
unnamed: D1.1, R3.1
unnamed: D2.1, R4.1
RTS#: Q1.2, Q2.1, U2.18
RX: J2.4, U2.17
RXLED#: R4.2, U2.29
TCK: J2.5, U2.38
TDI: J2.3, U2.39
TDO: J2.7, U2.40
TMS: J2.1, U2.41
TX: J2.2, U2.16
TXLED#: R3.2, U2.30
VBUS: C1.1, D1.2, D2.2, J1.1, U1.1, U1.3

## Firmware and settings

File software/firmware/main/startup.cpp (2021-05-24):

#include "error.h"
#include "events.h"
#include "filesystem.h"
#include "settings.h"
#include "gpio.h"
#include "ip.h"
#include "webserver.h"
#include "datetime.h"
#include "ota.h"
#include "dns/server.h"
#include "dns/dns.h"
#include "debug.h"

#include "nvs_flash.h"

#include <string>

extern "C" {
    void app_main();
}

#ifdef CONFIG_LOCAL_LOG_LEVEL
#define LOG_LOCAL_LEVEL ESP_LOG_INFO
#endif
#include "esp_log.h"
static const char *TAG = "BOOT";

// Simple macro that will rollback to previous version if any of the initialization steps fail
#define CHECK(x) if( x != ESP_OK ) rollback();

void set_logging_levels()
{
    esp_log_level_set("heap_init", ESP_LOG_ERROR);
    esp_log_level_set("wifi", ESP_LOG_ERROR);
    esp_log_level_set("wifi_init", ESP_LOG_ERROR);
    esp_log_level_set("system_api", ESP_LOG_ERROR);
    esp_log_level_set("esp_eth.netif.glue", ESP_LOG_ERROR);
    esp_log_level_set("esp_image", ESP_LOG_ERROR);
}

void init_event_bits(nvs_handle nvs)
{
    set_bit(INITIALIZING_BIT);

    bool eth = false;
    nvs_get_u8(nvs, "ethernet", (uint8_t*)&eth);
    if( eth )
    {
        ESP_LOGI(TAG, "Ethernet enabled");
        set_bit(ETH_ENABLED_BIT);
    }

    bool wifi = true;
    nvs_get_u8(nvs, "wifi", (uint8_t*)&wifi);
    if( wifi )
    {
        ESP_LOGI(TAG, "Wifi enabled");
        set_bit(WIFI_ENABLED_BIT);
    }

    bool gpio = false;
    if( nvs_get_i8(nvs, "gpio", (int8_t*)&gpio) == ESP_ERR_NVS_NOT_FOUND ){
        nvs_get_u8(nvs, "gpio", (uint8_t*)&gpio);
    }
    if( gpio )
    {
        ESP_LOGI(TAG, "GPIO enabled");
        set_bit(GPIO_ENABLED_BIT);
    }
}

static void verify_key(nvs_handle nvs, const char* key, uint8_t value)
{
    uint8_t buf = 0;                                                   
    esp_err_t status = nvs_get_u8(nvs, key, &buf);              
    if( status == ESP_ERR_NVS_NOT_FOUND )                           
    {                                                               
        ESP_LOGW(TAG, "%s not found, setting to %d", key, value);   
        status = nvs_set_u8(nvs, key, value);           
    }

    if( status != ESP_OK )                                     
    {                                                               
        THROWE(status, "Error verifying %s", key)                                              
    }                                                               
}

static esp_err_t verify_nvs(nvs_handle nvs)
{
    #ifdef CONFIG_GPIO_ENABLE
    verify_key(nvs, "gpio", CONFIG_GPIO_ENABLE);
    verify_key(nvs, "button", CONFIG_BUTTON);
    verify_key(nvs, "red_led", CONFIG_RED_LED);
    verify_key(nvs, "green_led", CONFIG_GREEN_LED);
    verify_key(nvs, "blue_led", CONFIG_BLUE_LED);
#endif
#ifdef CONFIG_ETHERNET_ENABLE
    verify_key(nvs, "ethernet", CONFIG_ETHERNET_ENABLE);
    verify_key(nvs, "phy_addr", CONFIG_ETH_PHY_ADDR);
    verify_key(nvs, "phy_rst", CONFIG_ETH_PHY_RST_GPIO);
    verify_key(nvs, "phy_mdio", CONFIG_ETH_MDIO_GPIO);
    verify_key(nvs, "phy_mdc", CONFIG_ETH_MDC_GPIO);
    #ifdef CONFIG_ETH_PHY_LAN8720
        verify_key(nvs, "phy", 1);
    #elif CONFIG_ETH_PHY_IP101
        verify_key(nvs, "phy", 2);
    #elif CONFIG_ETH_PHY_RTL8201
        verify_key(nvs, "phy", 3);
    #elif CONFIG_ETH_PHY_DP83848
        verify_key(nvs, "phy", 4);
    #endif
#endif
#ifdef CONFIG_WIFI_ENABLE
    verify_key(nvs, "wifi", CONFIG_WIFI_ENABLE);
#endif
    nvs_commit(nvs);

    return ESP_OK;
}

void init_nvs()
{
    ESP_LOGI(TAG, "Initializing NVS...");
    esp_err_t err = nvs_flash_init();
    if (err == ESP_ERR_NVS_NO_FREE_PAGES || err == ESP_ERR_NVS_NEW_VERSION_FOUND) {
        ESP_LOGE(TAG, "Error initializing flash, retrying..");
        err = nvs_flash_erase();
        if (err == ESP_OK){
            err = nvs_flash_init();
        }
    }
    if (err != ESP_OK){
        THROWE(err, "Failed to initialize nvs");
    }

    nvs_handle nvs;
    if ( (err = nvs_open("storage", NVS_READWRITE, &nvs)) != ESP_OK )
    {
        THROWE(err, "Failed to open nvs");
    }

    verify_nvs(nvs);
    init_event_bits(nvs);
}

void app_main()
{
    ESP_LOGI(TAG, "Booting...");
    set_logging_levels();

    try{
        init_stack_watcher();
        init_event_group();
        init_nvs();
        init_gpio();
        init_fs();
        init_interfaces();
        start_dns();

        start_interfaces();
        initialize_sntp();
        CHECK(start_webserver())
        CHECK(init_ota())
    } catch(const Err& e){
        ESP_LOGE(TAG, "Error during boot: %s", e.what());
        rollback();
    }

    cancel_rollback();
    wait_for(ETH_CONNECTED_BIT | WIFI_CONNECTED_BIT, portMAX_DELAY);
    clear_bit(INITIALIZING_BIT);
    try{
        check_for_update();
    }
    catch( const Err& e )
    {
        ESP_LOGE(TAG, "Error during OTA: %s", e.what());
    }
}

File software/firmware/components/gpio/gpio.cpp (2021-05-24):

#include "gpio.h"
#include "error.h"
#include "events.h"
#include "dns/dns.h"
#include "settings.h"
#include "filesystem.h"

#include "freertos/FreeRTOS.h"
#include "freertos/task.h"
#include "driver/gpio.h"
#include "driver/ledc.h"
#include "nvs_flash.h"

#ifdef CONFIG_LOCAL_LOG_LEVEL
#define LOG_LOCAL_LEVEL ESP_LOG_INFO
#endif
#include "esp_log.h"
static const char *TAG = "GPIO";

#define LED_SPEED_MODE LEDC_LOW_SPEED_MODE      // LED PWM speed mode
#define MAX_DUTY_CYCLE 1023                     // Duty cycle, picked 1023 so 0-255 values can be used for color 
#define FADE_TIME 1000                          // Fade time of 1 second

#define RED_LED_CHANNEL LEDC_CHANNEL_0          // Red LED Channel
#define GREEN_LED_CHANNEL LEDC_CHANNEL_1        // Green LED Channel
#define BLUE_LED_CHANNEL LEDC_CHANNEL_2         // Blue LED Channel

static gpio_num_t button = GPIO_NUM_NC;         // Button GPIO
static gpio_num_t red_led = GPIO_NUM_NC;        // Red LED GPIO
static gpio_num_t green_led = GPIO_NUM_NC;      // Green LED GPIO
static gpio_num_t blue_led = GPIO_NUM_NC;       // Blue LED GPIO

static TaskHandle_t button_task_handle;         // Task handle for button listening task
static TaskHandle_t led_task_handle;            // Task handle for LED task

static void button_state_change(void* arg)      // Button interrupt handler 
{
    xTaskNotifyFromISR(button_task_handle, 0, eNoAction, NULL);
}

static void button_task(void* args)             // Task keeping track of time between button presses
{
    uint32_t press_timestamp = 0xFFFFFFFF;
    uint32_t length = 0;

    while(1)
    {
        xTaskNotifyWait(0, 0, NULL, portMAX_DELAY);

        ESP_LOGV(TAG, "Reset Pin intr, val: %d", gpio_get_level(button));

        if(gpio_get_level(button) == 0) // Button is pressed down
        {
            press_timestamp = esp_log_timestamp();
        }
        else    // Button is released
        {
            length = esp_log_timestamp() - press_timestamp;
            ESP_LOGI(TAG, "Press time %d", length);
            if( length > 8000 )
            {
                ESP_LOGW(TAG, "Resetting");
                reset_fs();
            }
            else
            {
                bool blocking = !setting::read_bool(setting::BLOCK);
                setting::write(setting::BLOCK, blocking);
                blocking ? set_bit(BLOCKING_BIT) : clear_bit(BLOCKING_BIT);
            }
        }
    }
}

esp_err_t set_rgb(uint8_t red, uint8_t green, uint8_t blue)
{

    ledc_set_duty(LED_SPEED_MODE, RED_LED_CHANNEL, red*4);
    ledc_update_duty(LED_SPEED_MODE, RED_LED_CHANNEL);

    ledc_set_duty(LED_SPEED_MODE, GREEN_LED_CHANNEL, green*4);
    ledc_update_duty(LED_SPEED_MODE, GREEN_LED_CHANNEL);

    ledc_set_duty(LED_SPEED_MODE, BLUE_LED_CHANNEL, blue*4);
    ledc_update_duty(LED_SPEED_MODE, BLUE_LED_CHANNEL);

    return ESP_OK;
}

TaskHandle_t getLEDTaskHandle()
{
    return led_task_handle;
}

static void led_task(void* args)
{
    while(1)
    {
        vTaskDelay( 50/portTICK_RATE_MS );
        // wait_for( ALL_BITS, portMAX_DELAY); // wait for any bit
        if( check_bit(ERROR_BIT) )
        {
            set_rgb(RED);
        }
        else if( check_bit(INITIALIZING_BIT) )
        {
            set_rgb(PURPLE);
        }
        else if( check_bit(BLOCKED_QUERY_BIT) )
        {
            set_rgb(OFF);
            clear_bit(BLOCKED_QUERY_BIT);
        }
        else if( setting::read_bool(setting::BLOCK) )
        {
            set_rgb(BLUE);
        }
        else 
        {
            set_rgb(WEAK_BLUE);
        }
    }
}

static esp_err_t init_button()
{
    gpio_pad_select_gpio(button);
    ATTEMPT(gpio_set_direction(button, GPIO_MODE_INPUT))
    ATTEMPT(gpio_set_pull_mode(button, GPIO_PULLUP_ONLY))
    ATTEMPT(gpio_set_intr_type(button, GPIO_INTR_ANYEDGE))
    ATTEMPT(gpio_install_isr_service(0))
    ATTEMPT(gpio_isr_handler_add(button, button_state_change, NULL))
    
    return ESP_OK;
}
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

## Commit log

2021-04-11 Bugfixes for bugs found in first set of tests
    Bugsfixes:
    - Changed sdkconfig.defaults to use version in CMakeLists.txt
    - Added a provisioned flag in flash, fixing problem of Esper
    incorrectly thinking it was finished during provisioning
    - Added gpio_enabled checks in gpio.c so no errors would be
    thrown if gpio was disabled
    - OTA checking task now clers UPDATE_AVAILABLE flag
    - LED now shows correct state during initialization
    - Fixed build scripts
    Other:
    - Changed title of connected page
    - Increased max blacklist size to 50,000 bytes
    - Esper now connects to wifi if ethernet is disconnected
    - Blacklist now shows urls in reverse ordered, so the ones
    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
2021-04-12 Added LED blink when query is blocked
    Bugfixes:
    - Fixed bug in detecting restart after OTA
    - Corrected string formating (%*s to %.*s)
2021-04-16 Fixed bug in OTA rollback
    Logic for pushbutton timing was wrong, so device would
    never rollback no matter how long button is held
2021-04-22 Testing having blacklist in spiffs
    [configuration.csv]
2021-04-23 Still testing new webserver design
    [configuration.csv, log.csv]
2021-04-23 Working on wifi configuration
    [configuration.csv]
2021-04-25 Reworked provisioning mostly working
    also added a test server in website directory
    [configuration.csv]
2021-04-27 Finished provisioning server, added NVS checks
    [configuration.csv]
2021-04-28 Added blacklist add/remove, and changed to LittleFS
    [partitions_table.csv]
2021-05-07 Changed to new PHY
    [BOM.csv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]
2021-05-15 Completed testing
    [partitions_table.csv]
